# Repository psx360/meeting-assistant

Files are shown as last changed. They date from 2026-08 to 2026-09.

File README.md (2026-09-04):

# Meeting Assistant для Radxa ROCK 2F

Аппаратно-программный диктофон собраний: стереозапись с двух INMP441, управление кнопкой и OLED-платой HW-787AB, настройка Wi‑Fi по BLE, отложенная отправка при отсутствии сети, транскрибация на VPS и рассылка документов через Telegram/VK.

Репозиторий содержит исходники обеих частей системы и установщики для восстановления на чистых машинах. Секретные ключи, записи, база подписчиков и результаты встреч намеренно не входят в Git.

## Архитектура

1. Radxa записывает PulseAudio-источник INMP441 через FFmpeg в стерео Opus 48 кГц/64 кбит/с и делит поток на части по 10 минут.
2. Во время записи OLED показывает QR-код страницы подписки, таймер и уровень микрофона. Для остановки кнопку нужно удерживать не менее 1,5 секунды; подсказка на экране не занимает место.
3. Запись автоматически останавливается через 6 часов. После остановки QR остаётся на экране ещё 5 минут или до короткого нажатия кнопки.
4. После остановки части объединяются без повторного кодирования и помещаются в устойчивую локальную очередь. После скрытия QR OLED показывает процент подготовки и загрузки.
5. Таймер повторяет отправку на VPS; после скрытия QR OLED показывает «ОТПРАВКА» с процентами, а без сети — «ОЖИДАЕТ СЕТЬ», пока `.ready` не получил `.uploaded`.
6. VPS режет длинную запись на части по 20 минут и транскрибирует их моделью `gpt-4o-transcribe` с фиксированным языком `ru`.
7. Боты отправляют только два DOCX-файла: транскрибацию и протокол со сводкой. Постоянные подписчики получают все собрания, а перешедшие по QR — только выбранное.
8. В VK любое непустое текстовое сообщение включает постоянную подписку; команды отписки нет.

## Проверенная платформа

- Radxa ROCK 2F, Debian 12 (bookworm), Radxa kernel 6.1.43;
- 40-контактный GPIO-разъём;
- два цифровых микрофона INMP441 на SAI0/I2S0-M1;
- OLED/encoder HW-787AB, SSD1306-совместимый экран 128×64, I2C-адрес `0x3c`;
- отдельный Linux VPS с Debian/Ubuntu, Nginx и публичным HTTPS-доменом.

Другой образ ОС, нумерация GPIO или имя аудиоисточника могут потребовать адаптации констант.

## Подключение

Перед изменением проводов полностью отключайте питание. Номера ниже — физические номера контактов 40-pin разъёма.

### Два INMP441, стерео I2S0

| Сигнал INMP441 | Физический пин Radxa | Функция |
|---|---:|---|
| VDD обоих микрофонов | 17 | 3.3 V |
| GND обоих | 20 | GND |
| SCK/BCLK обоих | 12 | I2S0_SCLK_M1 / GPIO1_B5 |
| WS/LRCK обоих | 35 | I2S0_LRCK_M1 / GPIO1_B6 |
| SD обоих | 38 | I2S0_SDI_M1 / GPIO1_B7 |
| L/R первого | GND | левый канал |
| L/R второго | 3.3 V | правый канал |

Оба микрофона разделяют SCK, WS и SD; различаются только состоянием L/R.

### Кнопка записи

| Назначение | Подключение |
|---|---|
| Сигнальный контакт | физический пин 26, GPIO4_C1 (`gpiochip4`, line 17) |
| Подтяжка | 11 кОм от сигнала к 3.3 V |
| Второй контакт кнопки | GND |

Короткое нажатие запускает запись или убирает послесессионный QR-код. Во время записи короткое нажатие игнорируется; удержание не менее 1,5 секунды останавливает запись.

### HW-787AB

| Контакт платы | Физический пин Radxa | Назначение в ПО |
|---|---:|---|
| 3V3 | 1 или 17 | питание |
| GND | любой GND | земля |
| OLED_SDA | 32 | I2C0_SDA_M0 |
| OLED_SCL | 36 | I2C0_SCL_M0 |
| ENCODER_A | 11 | GPIO4_B7, line 15 |
| ENCODER_B | 13 | GPIO4_C0, line 16 |
| ENCODER_PUSH | 15 | GPIO4_C6, line 22 |
| BACK | 29 | GPIO4_B5, line 13 |
| CONFIRM | 31 | GPIO1_B0, `gpiochip1`, line 8 |

Пины `OLED_SDA/SCL` не совпадают с I2S и могут работать одновременно. WS2812B из окончательной конфигурации исключён: без преобразователя уровня 3.3→5 V управление было ненадёжным.

## Восстановление Radxa

На чистом Debian 12:

```bash
sudo apt-get update
sudo apt-get install -y git
git clone https://github.com/psx360/meeting-assistant.git
cd meeting-assistant
sudo ./install-radxa.sh
sudo nano /home/radxa/.config/meeting-upload.env
sudo reboot
```

В `meeting-upload.env` задайте публичный HTTPS URL VPS и общий `MEETING_API_TOKEN`. Установщик:

- ставит FFmpeg, SoX, PipeWire, BlueZ, NetworkManager, gpiod и зависимости Python;
- компилирует и подключает оба DT-overlay;
- устанавливает системные и пользовательские systemd-службы;
- включает watchdog Wi‑Fi и повторную отправку очереди;
- сохраняет резервную копию `extlinux.conf` как `extlinux.conf.meeting-assistant.bak`.

В меню OLED пункт «IP АДРЕС» показывает текущий IPv4-адрес Wi‑Fi интерфейса.

После перезагрузки проверьте:

```bash
arecord -l
pactl list short sources
i2cdetect -y 0
systemctl status recorder-controller oled-dashboard wifi-watchdog
systemctl --user status meeting-upload.timer
journalctl -f -u recorder-controller -u oled-dashboard
```

Ожидаемый источник: `alsa_input.platform-inmp441-sound.stereo-fallback`, OLED — `0x3c`.

Коэффициент программного усиления по умолчанию задаётся как `MIC_GAIN=4`. Значение можно изменить в BLE-форме; оно сохраняется в `/var/lib/meeting-recorder/settings.json` и применяется после перезагрузки и при каждом новом запуске записи.

## Восстановление VPS

```bash
sudo apt-get update
sudo apt-get install -y git
git clone https://github.com/psx360/meeting-assistant.git
cd meeting-assistant
sudo ./install-vps.sh
sudo nano /etc/meeting-assistant.env
sudo systemctl restart meeting-assistant meeting-worker
```

Заполните все поля из `vps.env.example`. `MEETING_API_TOKEN` должен побайтно совпадать со значением на Radxa. Затем замените `server_name _` в `/etc/nginx/sites-available/meeting-assistant` на домен и настройте HTTPS. Telegram и VK требуют публичный HTTPS callback URL.

Регистрация Telegram webhook после настройки `PUBLIC_BASE_URL`:

```bash
sudo python3 register-meeting-telegram-webhook.py
```

Для VK укажите callbacks:

- `https://ВАШ-ДОМЕН/vk/callback`;
- confirmation code, secret, group ID и community access token — в `/etc/meeting-assistant.env`.
- `VK_GROUP_SCREEN_NAME` можно задать коротким именем сообщества; иначе страница подписки использует `club<VK_GROUP_ID>`.

Проверка:

```bash
curl http://127.0.0.1:8090/health
systemctl status meeting-assistant meeting-worker nginx
journalctl -f -u meeting-assistant -u meeting-worker
```

Данные VPS находятся в `/var/lib/meeting-assistant`:

- `incoming/` — очередь;
- `completed/<meeting-id>/transcript-raw.txt` — исходное распознавание;
- `completed/<meeting-id>/transcript.txt` — исходная русская транскрипция без диаризации и пересказа;
- `completed/<meeting-id>/summary.txt` — структурированный протокол и сводка встречи.

Для подписчиков Telegram результат приходит в таком порядке:

1. DOCX с полной транскрибацией одним документом.
2. DOCX с протоколом и сводкой: тезисы, решения, организационные выводы, поручения и нерешённые вопросы — только если они были в разговоре.
3. Полный текст транскрибации, автоматически разбитый на несколько сообщений Telegram.
- `completed/<meeting-id>/protocol.txt` — отправленный протокол;
- `meeting-assistant.sqlite3` — подписчики и статусы рассылки.

Эти данные резервируются отдельно от Git.

## BLE-настройка

Нажмите энкодер на экране готовности и выберите режим BT. Устройство рекламируется как `Meeting Assistant`. Веб-форма находится в `bluefy-setup.html` и предназначена для открытия в iOS-браузере Bluefy. Она позволяет найти похожее имя Wi‑Fi, передать пароль или выбрать открытую сеть, изменить пороги речи/тишины и выполнить 10-секундный замер шума.

## Основные журналы

```bash
# Radxa: кнопка, запись, OLED, загрузка
journalctl -f -u recorder-controller -u oled-dashboard -u wifi-watchdog
journalctl --user -f -u audio-recorder -u meeting-upload

# VPS: приём, транскрибация и рассылка
journalctl -f -u meeting-assistant -u meeting-worker
```

## Безопасность и резервное копирование

Никогда не добавляйте в Git `.env`, `*.key`, базу SQLite и записи. Для полного аварийного восстановления отдельно сохраняйте:

- `/etc/meeting-assistant.env` на VPS;
- `/var/lib/meeting-assistant/meeting-assistant.sqlite3`;
- `/home/radxa/.config/meeting-upload.env`;
- при необходимости каталоги `completed/` и записи на Radxa.

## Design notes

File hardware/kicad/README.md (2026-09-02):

# KiCad hardware schematic

Editable schematic for the assembled Meeting Assistant. It documents wiring to the Radxa ROCK 2F header; it is not a custom PCB layout.

Open `meeting-assistant.kicad_pro` with KiCad 10, or regenerate the schematic with the Python API used by the KiCad MCP ecosystem:

```powershell
$env:KICAD_SYMBOL_DIR="C:\Program Files\KiCad\10.0\share\kicad\symbols"
python -m pip install kicad-sch-api
python generate_schematic.py
```

For a per-user KiCad installation, adjust `KICAD_SYMBOL_DIR` to `%LOCALAPPDATA%\Programs\KiCad\10.0\share\kicad\symbols`.

The net labels encode the actual physical-pin mapping. Equal labels are electrically connected even where a long wire is intentionally avoided for readability.

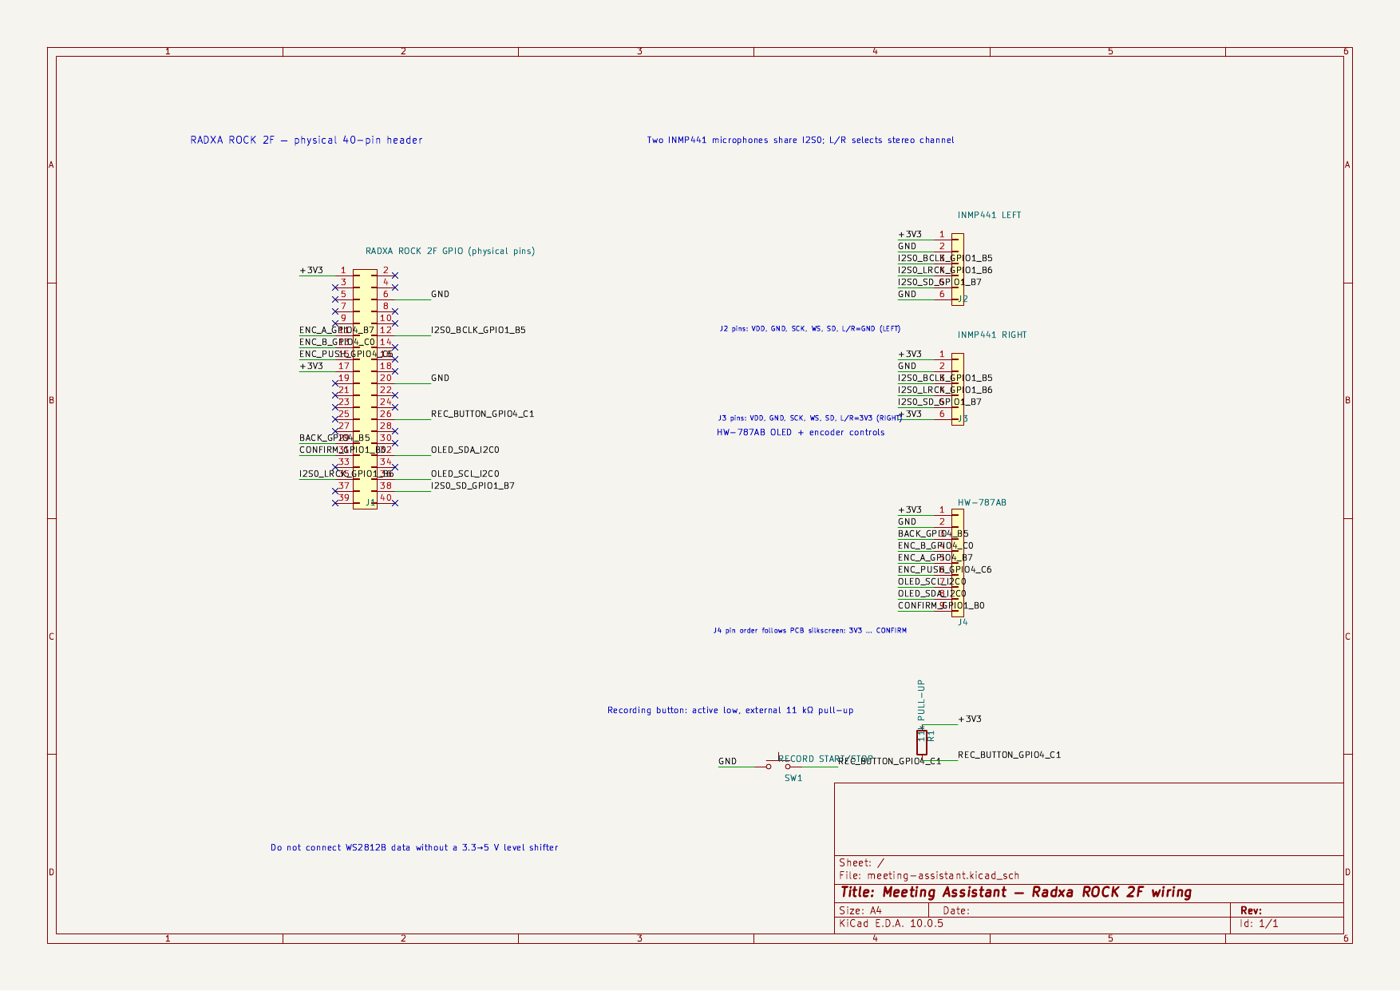
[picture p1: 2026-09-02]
hardware/kicad/export/meeting-assistant-preview.png

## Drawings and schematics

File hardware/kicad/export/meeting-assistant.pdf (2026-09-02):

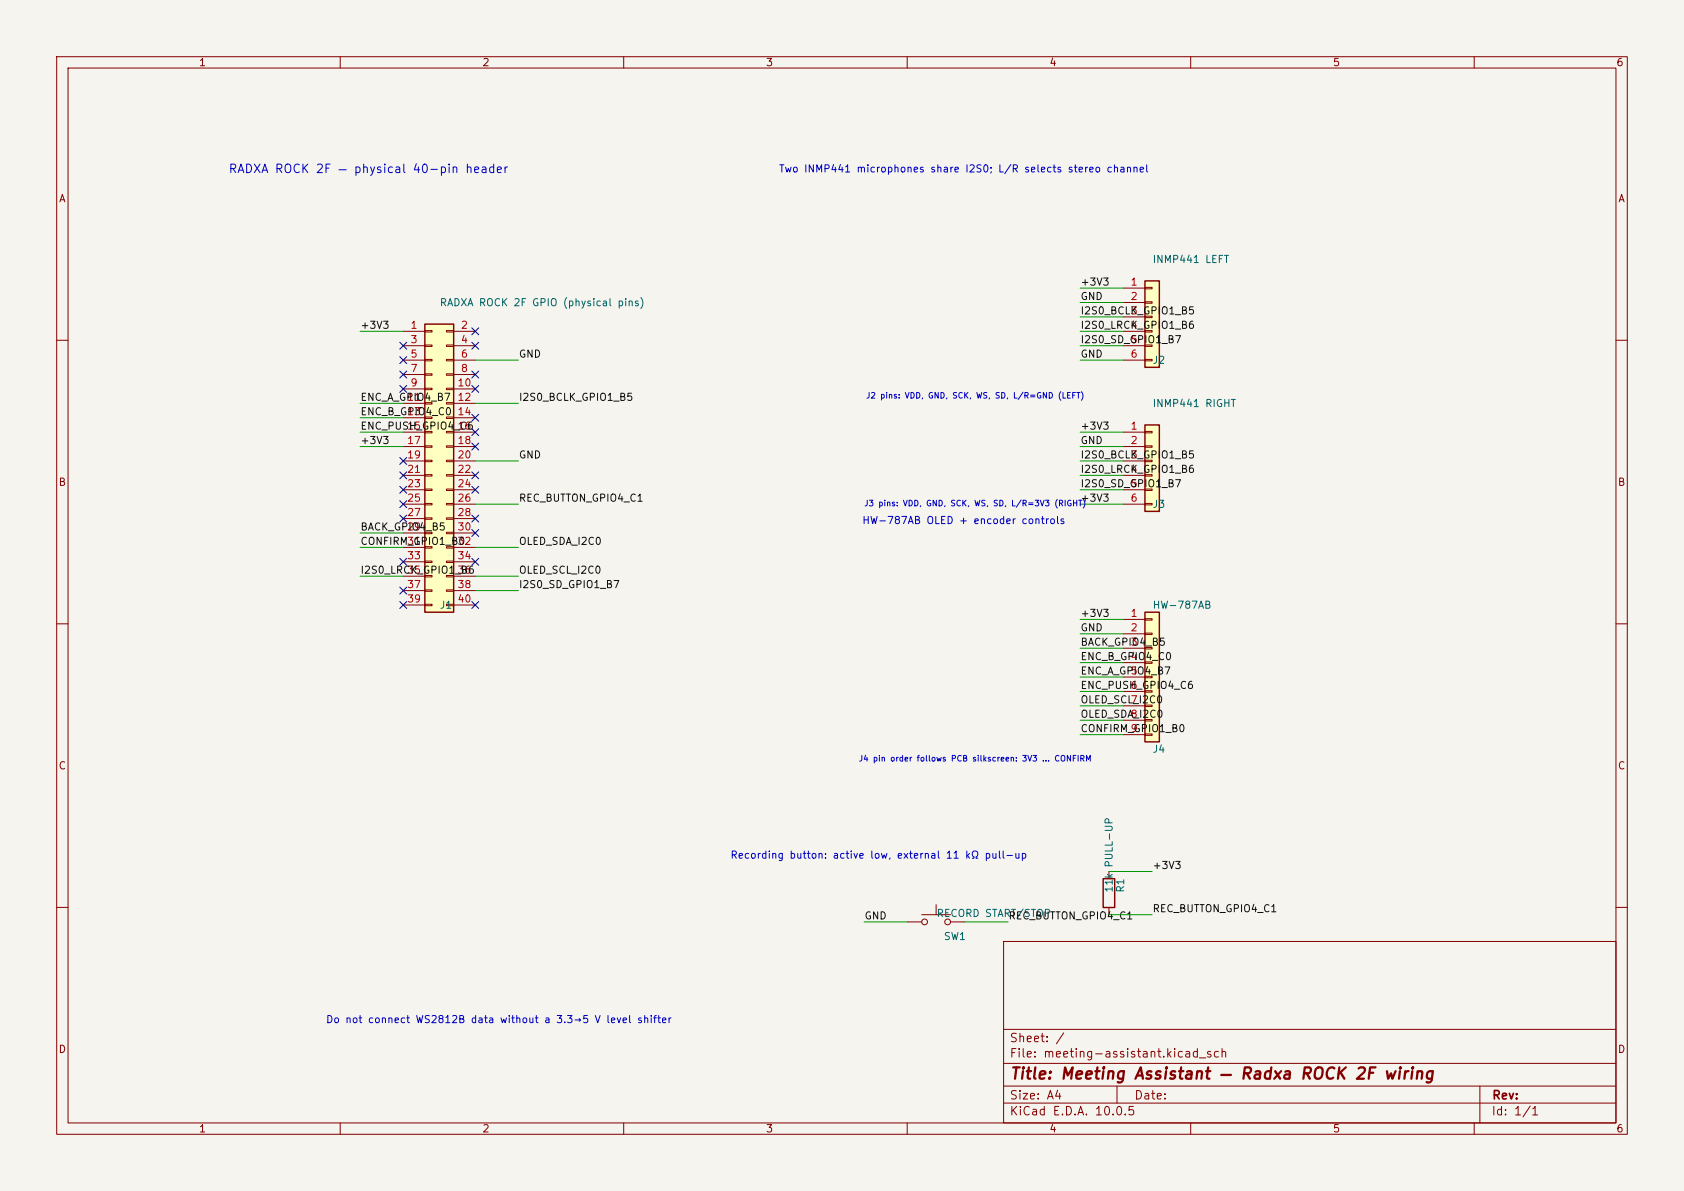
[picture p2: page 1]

J3 pins: VDD, GND, SCK, WS, SD, L/R=3V3 (RIGHT) Do not connect WS2812B data without a 3.3→5 V level shifter

J4 pin order follows PCB silkscreen: 3V3 … CONFIRM

Recording button: active low, external 11 kΩ pull-up

Sheet: /
File: meeting-assistant.kicad_sch
Title: Meeting Assistant — Radxa ROCK 2F wiring

Size: A4 | Rev:
KiCad E.D.A. 10.0.5 | Id: 1/1

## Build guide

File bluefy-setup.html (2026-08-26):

# Meeting Assistant

Настройка устройства по Bluetooth

## Bluetooth не подключён

Подключить устройствоОтключить

На диктофоне откройте меню и включите «BT СОПРЯЖЕНИЕ», затем выберите Meeting Assistant.

## Wi‑Fi

Название или похожая часть названия сети

Пароль

Открытая сеть, без пароля

Найти сетиСохранить и подключить

## Чувствительность к речи

Усиление микрофона

Сохранить усиление

Шум комнаты, dB

Порог речи, dB

Порог тишины, dB

Измерить шум 10 секундПрименить измеренноеСохранить порог

Во время измерения соблюдайте тишину. Порог речи устанавливается на 4 dB выше порога тишины.

## Состояние

Сначала подключите устройство.

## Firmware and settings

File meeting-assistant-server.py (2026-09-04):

#!/usr/bin/python3
import base64
import hashlib
import hmac
import html
import json
import importlib.util
import logging
import os
import re
import secrets
import sqlite3
import time
import urllib.parse
import urllib.request
import uuid
from http.server import BaseHTTPRequestHandler, ThreadingHTTPServer


HOST = "127.0.0.1"
PORT = int(os.environ.get("MEETING_ASSISTANT_PORT", "8090"))
DB_PATH = os.environ.get("MEETING_DB_PATH", "/var/lib/meeting-assistant/meeting-assistant.sqlite3")
INCOMING_DIR = os.environ.get("MEETING_INCOMING_DIR", "/var/lib/meeting-assistant/incoming")
MAX_UPLOAD_BYTES = 256 * 1024 * 1024
TELEGRAM_KEY = os.environ.get("TELEGRAM_KEY", "")
TELEGRAM_WEBHOOK_SECRET = os.environ.get("TELEGRAM_WEBHOOK_SECRET", "")
MEETING_API_TOKEN = os.environ.get("MEETING_API_TOKEN", "")
VK_CONFIRMATION_CODE = os.environ.get("VK_CONFIRMATION_CODE", "")
VK_SECRET = os.environ.get("VK_SECRET", "")
VK_GROUP_ID = os.environ.get("VK_GROUP_ID", "")
VK_GROUP_TOKEN = os.environ.get("VK_GROUP_TOKEN", "")
VK_GROUP_SCREEN_NAME = os.environ.get("VK_GROUP_SCREEN_NAME", "")
VK_API_VERSION = "5.199"
JOIN_SIGNATURE_BYTES = 12
JOIN_SIGNATURE_CHARS = len(base64.urlsafe_b64encode(b"\0" * JOIN_SIGNATURE_BYTES).decode().rstrip("="))

logging.basicConfig(level=logging.INFO, format="%(message)s")
log = logging.getLogger("meeting-assistant")

_documents_spec = importlib.util.spec_from_file_location(
    "meeting_documents", os.path.join(os.path.dirname(__file__), "meeting-documents.py")
)
meeting_documents = importlib.util.module_from_spec(_documents_spec)
_documents_spec.loader.exec_module(meeting_documents)


def db_connect():
    connection = sqlite3.connect(DB_PATH, timeout=30)
    connection.execute("PRAGMA journal_mode=WAL")
    connection.execute("PRAGMA busy_timeout=30000")
    return connection


def init_db():
    os.makedirs(INCOMING_DIR, exist_ok=True)
    with db_connect() as db:
        db.executescript(
            """
            CREATE TABLE IF NOT EXISTS subscribers (
                platform TEXT NOT NULL,
                recipient_id TEXT NOT NULL,
                active INTEGER NOT NULL DEFAULT 1,
                subscribed_at INTEGER NOT NULL,
                updated_at INTEGER NOT NULL,
                PRIMARY KEY (platform, recipient_id)
            );
            CREATE TABLE IF NOT EXISTS broadcasts (
                meeting_id TEXT PRIMARY KEY,
                title TEXT NOT NULL,
                transcript TEXT NOT NULL DEFAULT '',
                protocol TEXT NOT NULL,
                created_at INTEGER NOT NULL
            );
            CREATE TABLE IF NOT EXISTS deliveries (
                meeting_id TEXT NOT NULL,
                platform TEXT NOT NULL,
                recipient_id TEXT NOT NULL,
                status TEXT NOT NULL,
                error TEXT,
                updated_at INTEGER NOT NULL,
                PRIMARY KEY (meeting_id, platform, recipient_id)
            );
            CREATE TABLE IF NOT EXISTS meeting_subscriptions (
                meeting_id TEXT NOT NULL,
                platform TEXT NOT NULL,
                recipient_id TEXT NOT NULL,
                active INTEGER NOT NULL DEFAULT 1,
                subscribed_at INTEGER NOT NULL,
                updated_at INTEGER NOT NULL,
                PRIMARY KEY (meeting_id, platform, recipient_id)
            );
            """
        )
        broadcast_columns = {row[1] for row in db.execute("PRAGMA table_info(broadcasts)")}
        if "transcript" not in broadcast_columns:
            db.execute("ALTER TABLE broadcasts ADD COLUMN transcript TEXT NOT NULL DEFAULT ''")


def set_subscription(platform, recipient_id, active):
    now = int(time.time())
    with db_connect() as db:
        db.execute(
            """INSERT INTO subscribers(platform, recipient_id, active, subscribed_at, updated_at)
               VALUES (?, ?, ?, ?, ?)
               ON CONFLICT(platform, recipient_id) DO UPDATE
               SET active=excluded.active, updated_at=excluded.updated_at""",
            (platform, str(recipient_id), int(active), now, now),
        )
    log.info("SUBSCRIPTION platform=%s recipient=%s active=%s", platform, recipient_id, str(active).lower())


def set_meeting_subscription(meeting_id, platform, recipient_id, active=True):
    now = int(time.time())
    with db_connect() as db:
        db.execute(
            """INSERT INTO meeting_subscriptions(meeting_id, platform, recipient_id, active, subscribed_at, updated_at)
               VALUES (?, ?, ?, ?, ?, ?)
               ON CONFLICT(meeting_id, platform, recipient_id) DO UPDATE
               SET active=excluded.active, updated_at=excluded.updated_at""",
            (meeting_id, platform, str(recipient_id), int(active), now, now),
        )
    log.info(
        "MEETING_SUBSCRIPTION meeting=%s platform=%s recipient=%s active=%s",
        meeting_id, platform, recipient_id, str(active).lower(),
    )
    if active:
        deliver_existing_meeting(meeting_id, platform, str(recipient_id))


def join_payload(meeting_id):
    if not MEETING_API_TOKEN or not re.fullmatch(r"[A-Za-z0-9._-]{1,200}", meeting_id):
        return ""
    digest = hmac.new(MEETING_API_TOKEN.encode(), meeting_id.encode(), hashlib.sha256).digest()
    signature = base64.urlsafe_b64encode(digest[:JOIN_SIGNATURE_BYTES]).decode().rstrip("=")
    return f"m_{meeting_id}_{signature}"


def meeting_id_from_payload(payload):
    if not re.fullmatch(r"m_[A-Za-z0-9._-]{1,240}", payload or ""):
        return ""
    value = payload[2:]
    separator = len(value) - JOIN_SIGNATURE_CHARS - 1
    if separator <= 0 or value[separator] != "_":
        return ""
    meeting_id = value[:separator]
    expected = join_payload(meeting_id)
    return meeting_id if expected and secrets.compare_digest(payload, expected) else ""


def chunks(text, limit=3500):
    text = text.strip()
    while text:
        if len(text) <= limit:
            yield text
            return
        split_at = text.rfind("\n", 0, limit)
        if split_at < limit // 2:
            split_at = text.rfind(" ", 0, limit)
        if split_at < limit // 2:
            split_at = limit
        yield text[:split_at].rstrip()
        text = text[split_at:].lstrip()


def post_form(url, fields):
    payload = urllib.parse.urlencode(fields).encode()
    request = urllib.request.Request(url, data=payload, method="POST")
    with urllib.request.urlopen(request, timeout=20) as response:
        return json.load(response)


def post_multipart(url, fields, file_field, filename, content, content_type):
    boundary = "----meeting-" + uuid.uuid4().hex
    body = bytearray()
    for name, value in fields.items():
        body.extend(f"--{boundary}\r\nContent-Disposition: form-data; name=\"{name}\"\r\n\r\n{value}\r\n".encode("utf-8"))
    body.extend(
        f"--{boundary}\r\nContent-Disposition: form-data; name=\"{file_field}\"; filename=\"{filename}\"\r\n"
        f"Content-Type: {content_type}\r\n\r\n".encode("utf-8")
    )
    body.extend(content)
    body.extend(f"\r\n--{boundary}--\r\n".encode("ascii"))
    request = urllib.request.Request(
        url, data=body, headers={"Content-Type": f"multipart/form-data; boundary={boundary}"}, method="POST"
    )
    with urllib.request.urlopen(request, timeout=60) as response:
        return json.load(response)


def telegram(method, fields):
    if not TELEGRAM_KEY:
        raise RuntimeError("Telegram token is not configured")
    result = post_form(f"https://api.telegram.org/bot{TELEGRAM_KEY}/{method}", fields)
    if not result.get("ok"):
        raise RuntimeError(result.get("description", "Telegram API error"))
    return result


def telegram_send(chat_id, text):
    for part in chunks(text):
        telegram("sendMessage", {"chat_id": chat_id, "text": part})


def telegram_document(chat_id, filename, content):
    if not TELEGRAM_KEY:
        raise RuntimeError("Telegram token is not configured")
    result = post_multipart(
        f"https://api.telegram.org/bot{TELEGRAM_KEY}/sendDocument",
        {"chat_id": str(chat_id)}, "document", filename, content,
        "application/vnd.openxmlformats-officedocument.wordprocessingml.document",
    )
    if not result.get("ok"):
        raise RuntimeError(result.get("description", "Telegram API error"))
    return result


_telegram_username = ""


def telegram_bot_username():
    global _telegram_username
    if not _telegram_username:
        result = telegram("getMe", {})
        _telegram_username = str((result.get("result") or {}).get("username", "")).lstrip("@")
    return _telegram_username


def vk(method, fields):
    if not VK_GROUP_TOKEN:
        raise RuntimeError("VK group access token is not configured")
    fields.update({"access_token": VK_GROUP_TOKEN, "v": VK_API_VERSION})
    result = post_form(f"https://api.vk.com/method/{method}", fields)
    if "error" in result:
        raise RuntimeError(result["error"].get("error_msg", "VK API error"))
    return result


def vk_send(peer_id, text):
    for part in chunks(text):
        vk("messages.send", {"peer_id": peer_id, "random_id": secrets.randbelow(2_147_483_647), "message": part})


def vk_document_attachment(peer_id, filename, content):
    file_token = ""
    for attempt in range(1, 4):
        upload = vk("docs.getMessagesUploadServer", {"peer_id": peer_id, "type": "doc"}).get("response") or {}
        upload_url = upload.get("upload_url", "")
        if not upload_url:
            raise RuntimeError("VK did not return a document upload URL")
        uploaded = post_multipart(
            upload_url, {}, "file", filename, content,
            "application/vnd.openxmlformats-officedocument.wordprocessingml.document",
        )
        file_token = uploaded.get("file", "")
        if file_token:
            break
        log.warning("VK_DOCUMENT_UPLOAD_RETRY peer=%s file=%s attempt=%d", peer_id, safe_filename(filename), attempt)
        if attempt < 3:
            time.sleep(0.5 * attempt)
    if not file_token:
        raise RuntimeError("VK document upload did not return a file token after 3 attempts")
    saved = vk("docs.save", {"file": file_token, "title": filename}).get("response")
    if isinstance(saved, list):
        document = saved[0] if saved else {}
    elif isinstance(saved, dict) and isinstance(saved.get("doc"), dict):
        document = saved["doc"]
    else:
        document = saved or {}
    owner_id, document_id = document.get("owner_id"), document.get("id")
    if owner_id is None or document_id is None:
        raise RuntimeError("VK docs.save did not return a document identifier")
    attachment = f"doc{owner_id}_{document_id}"
    if document.get("access_key"):
        attachment += f"_{document['access_key']}"
    return attachment


def vk_send_documents(peer_id, documents):
    attachments = [vk_document_attachment(peer_id, filename, content) for filename, content in documents]
    vk("messages.send", {
        "peer_id": peer_id,
        "random_id": secrets.randbelow(2_147_483_647),
        "attachment": ",".join(attachments),
    })


def subscription_command(text):
    command = text.strip().lower().split(maxsplit=1)[0] if text.strip() else ""
    if "@" in command:
        command = command.split("@", 1)[0]
    if command in {"/start", "/subscribe", "подписаться", "старт", "start", "subscribe"}:
        return True
    if command in {"/stop", "/unsubscribe", "отписаться", "стоп", "stop", "unsubscribe"}:
        return False
    return None


def telegram_meeting_payload(text):
    parts = text.strip().split(maxsplit=1)
    if len(parts) != 2:
        return ""
    command = parts[0].lower().split("@", 1)[0]
    return parts[1].strip() if command == "/start" else ""


def handle_telegram(update):
    message = update.get("message") or {}
    chat_id = (message.get("chat") or {}).get("id")
    if not chat_id:
        return
    text = message.get("text", "")
    payload = telegram_meeting_payload(text)
    if payload:
        meeting_id = meeting_id_from_payload(payload)
        if meeting_id:
            set_meeting_subscription(meeting_id, "telegram", chat_id)
            telegram_send(chat_id, "Вы подписаны только на документы этого собрания.")
        else:
            telegram_send(chat_id, "Ссылка на собрание недействительна.")
        return
    command = subscription_command(text)
    if command is True:
        set_subscription("telegram", chat_id, True)
        telegram_send(chat_id, "Вы подписаны на протоколы собраний. Для отмены: /unsubscribe")
    elif command is False:
        set_subscription("telegram", chat_id, False)
        telegram_send(chat_id, "Подписка на протоколы собраний отключена. Для возобновления: /subscribe")
    else:
        telegram_send(chat_id, "Команды: /subscribe — получать протоколы, /unsubscribe — отключить рассылку.")


def handle_vk(event):
    event_type = event.get("type", "")
    obj = event.get("object") or {}
    if event_type == "message_allow":
        user_id = obj.get("user_id")
        if user_id:
            set_subscription("vk", user_id, True)
        return
    if event_type == "message_deny":
        user_id = obj.get("user_id")
        if user_id:
            set_subscription("vk", user_id, False)
        return
    if event_type != "message_new":
        return
    message = obj.get("message") or {}
    peer_id = message.get("peer_id") or message.get("from_id")
    if not peer_id:
        return
    meeting_id = meeting_id_from_payload(str(message.get("ref", "")))
    if meeting_id:
        set_meeting_subscription(meeting_id, "vk", peer_id)
        vk_send(peer_id, "Вы подписаны только на документы этого собрания.")
        return
    text = str(message.get("text", "")).strip()
    if text:
        set_subscription("vk", peer_id, True)
        vk_send(peer_id, "Вы подписаны на протоколы собраний.")
    else:
        vk_send(peer_id, "Отправьте любое текстовое сообщение, чтобы подписаться на протоколы собраний.")


def safe_filename(value):
    value = re.sub(r"[^A-Za-zА-Яа-яЁё0-9._ -]+", "_", value).strip(" ._")
    return value[:100] or "Собрание"


def meeting_page(payload):
    meeting_id = meeting_id_from_payload(payload)
    if not meeting_id:
        return 404, "Ссылка на собрание недействительна."
    try:
        telegram_username = telegram_bot_username()
    except Exception:
        log.exception("TELEGRAM_USERNAME_LOOKUP_FAILED")
        telegram_username = ""
    vk_name = VK_GROUP_SCREEN_NAME.strip().lstrip("@") or (f"club{VK_GROUP_ID}" if VK_GROUP_ID else "")
    telegram_url = f"https://t.me/{telegram_username}?start={urllib.parse.quote(payload)}" if telegram_username else ""
    vk_url = (
        f"https://vk.me/{urllib.parse.quote(vk_name)}?"
        + urllib.parse.urlencode({"ref": payload, "ref_source": "meeting_qr"})
        if vk_name else ""
    )
    buttons = []
    if telegram_url:
        buttons.append(f'<a class="button telegram" href="{html.escape(telegram_url, quote=True)}">Подписаться в Telegram</a>')
    if vk_url:
        buttons.append(f'<a class="button vk" href="{html.escape(vk_url, quote=True)}">Подписаться во ВКонтакте</a>')
    if not buttons:
        buttons.append('<p class="error">Ссылки на ботов пока не настроены.</p>')
    page = f"""<!doctype html>
<html lang="ru"><head><meta charset="utf-8"><meta name="viewport" content="width=device-width,initial-scale=1">
<meta name="theme-color" content="#14213d"><title>Подписка на собрание</title>
<style>
:root{{font-family:-apple-system,BlinkMacSystemFont,"Segoe UI",sans-serif;color:#152238;background:#eef2f7}}
*{{box-sizing:border-box}}body{{margin:0;padding:24px 16px}}main{{max-width:520px;margin:auto;background:#fff;border-radius:20px;padding:26px;box-shadow:0 12px 35px #1e293b20}}
h1{{margin:0 0 10px;font-size:27px}}p{{line-height:1.5;color:#526174}}.meeting{{font-family:ui-monospace,monospace;background:#f1f5f9;border-radius:10px;padding:10px 12px;word-break:break-all}}
.button{{display:block;margin:13px 0;padding:15px 18px;border-radius:12px;color:#fff;text-decoration:none;text-align:center;font-weight:700}}.telegram{{background:#229ed9}}.vk{{background:#0077ff}}.note{{font-size:13px}}.error{{color:#b91c1c}}
</style></head><body><main><h1>Документы собрания</h1>
<p>Выберите бот. Подписка действует только для этого собрания: после обработки бот пришлёт протокол и транскрибацию в DOCX.</p>
<div class="meeting">{html.escape(meeting_id)}</div>{''.join(buttons)}
<p class="note">В Telegram нажмите «Старт». Во ВКонтакте откройте диалог и отправьте любое сообщение — метка собрания передастся боту автоматически.</p>
</main></body></html>"""
    return 200, page


def document_payloads(title, transcript, summary):
    stem = safe_filename(title)
    return [
        (f"{stem} - транскрибация.docx", meeting_documents.build_docx(f"{title} — транскрибация", transcript)),
        (f"{stem} - протокол и сводка.docx", meeting_documents.build_docx(f"{title} — протокол и сводка", summary, structured=True)),
    ]


def claim_delivery(meeting_id, platform, recipient_id):
    with db_connect() as db:
        result = db.execute(
            """INSERT INTO deliveries(meeting_id, platform, recipient_id, status, error, updated_at)
               VALUES (?, ?, ?, 'sending', NULL, ?)
               ON CONFLICT(meeting_id, platform, recipient_id) DO UPDATE
               SET status='sending', error=NULL, updated_at=excluded.updated_at
               WHERE deliveries.status='failed'""",
            (meeting_id, platform, str(recipient_id), int(time.time())),
        )
        return result.rowcount == 1


def finish_delivery(meeting_id, platform, recipient_id, status, error=None):
    with db_connect() as db:
        db.execute(
            """UPDATE deliveries SET status=?, error=?, updated_at=?
               WHERE meeting_id=? AND platform=? AND recipient_id=?""",
            (status, error, int(time.time()), meeting_id, platform, str(recipient_id)),
        )


def send_document_payloads(platform, recipient_id, documents):
    if platform == "telegram":
        for filename, content in documents:
            telegram_document(recipient_id, filename, content)
    elif platform == "vk":
        vk_send_documents(recipient_id, documents)
    else:
        raise RuntimeError("unknown platform")


def deliver_existing_meeting(meeting_id, platform, recipient_id):
    with db_connect() as db:
        completed = db.execute(
            "SELECT title, transcript, protocol FROM broadcasts WHERE meeting_id=?",
            (meeting_id,),
        ).fetchone()
    if not completed or not completed[1] or not claim_delivery(meeting_id, platform, recipient_id):
        return False
    try:
        send_document_payloads(platform, recipient_id, document_payloads(*completed))
        finish_delivery(meeting_id, platform, recipient_id, "sent")
        log.info("LATE_DELIVERY_FINISHED meeting=%s platform=%s recipient=%s", meeting_id, platform, recipient_id)
        return True
    except Exception as exc:
        error = str(exc)[:500]
        finish_delivery(meeting_id, platform, recipient_id, "failed", error)
        log.error("LATE_DELIVERY_FAILED meeting=%s platform=%s recipient=%s error=%s", meeting_id, platform, recipient_id, error)
        return False


def broadcast(meeting_id, title, transcript, summary):
    now = int(time.time())
    with db_connect() as db:
        existing = db.execute("SELECT 1 FROM broadcasts WHERE meeting_id=?", (meeting_id,)).fetchone()
        if existing:
            return {"duplicate": True, "sent": 0, "failed": 0}
        db.execute(
            "INSERT INTO broadcasts(meeting_id, title, transcript, protocol, created_at) VALUES (?, ?, ?, ?, ?)",
            (meeting_id, title, transcript, summary, now),
        )
        recipients = db.execute(
            """SELECT platform, recipient_id FROM subscribers WHERE active=1
               UNION
               SELECT platform, recipient_id FROM meeting_subscriptions WHERE meeting_id=? AND active=1
               ORDER BY platform, recipient_id""",
            (meeting_id,),
        ).fetchall()

    documents = document_payloads(title, transcript, summary)
    sent = failed = 0
    for platform, recipient_id in recipients:
        if not claim_delivery(meeting_id, platform, recipient_id):
            continue
        try:
            send_document_payloads(platform, recipient_id, documents)
            status, error = "sent", None
            sent += 1
        except Exception as exc:
            status, error = "failed", str(exc)[:500]
            failed += 1
            log.error("DELIVERY_FAILED meeting=%s platform=%s recipient=%s error=%s", meeting_id, platform, recipient_id, error)
        finish_delivery(meeting_id, platform, recipient_id, status, error)
    log.info("BROADCAST_FINISHED meeting=%s sent=%d failed=%d", meeting_id, sent, failed)
    return {"duplicate": False, "sent": sent, "failed": failed}
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

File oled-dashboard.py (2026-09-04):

#!/usr/bin/python3
import array, fcntl, glob, json, math, os, signal, subprocess, threading, time
import gpiod
try:import qrcode
except ImportError:qrcode=None
I2C_DEV="/dev/i2c-0"; I2C_ADDR=0x3C; STATE_FILE="/run/ai-recorder-state"; LEVEL_FILE="/run/ai-recorder-audio-level"
UPLOAD_PROGRESS_FILE="/run/user/1000/meeting-upload-progress.json"; AUTO_STOP_SECONDS=6*3600; AUTO_STOP_WARNING_SECONDS=15*60
MEETING_DISPLAY_FILE="/run/user/1000/meeting-display.json"
MEETING_DISPLAY_DISMISSED_FILE="/run/user/1000/meeting-display-dismissed"
SOURCE="alsa_input.platform-inmp441-sound.stereo-fallback"
DEFAULT_MIC_GAIN=float(os.environ.get("MIC_GAIN","4"))
SETTINGS_FILE="/var/lib/meeting-recorder/settings.json"
FONT={
" ":[0,0,0,0,0],"-":[8,8,8,8,8],".":[0,0,0,96,96],":":[0,54,54,0,0],"/":[64,32,16,8,4],"!":[0,0,95,0,0],"?":[2,1,81,9,6],
"0":[62,81,73,69,62],"1":[0,66,127,64,0],"2":[66,97,81,73,70],"3":[33,65,69,75,49],"4":[24,20,18,127,16],"5":[39,69,69,69,57],"6":[60,74,73,73,48],"7":[1,113,9,5,3],"8":[54,73,73,73,54],"9":[6,73,73,41,30],
"A":[126,17,17,17,126],"B":[127,73,73,73,54],"C":[62,65,65,65,34],"D":[127,65,65,34,28],"E":[127,73,73,73,65],"F":[127,9,9,9,1],"G":[62,65,73,73,122],"H":[127,8,8,8,127],"I":[0,65,127,65,0],"J":[32,64,65,63,1],"K":[127,8,20,34,65],"L":[127,64,64,64,64],"M":[127,2,12,2,127],"N":[127,4,8,16,127],"O":[62,65,65,65,62],"P":[127,9,9,9,6],"Q":[62,65,81,33,94],"R":[127,9,25,41,70],"S":[38,73,73,73,50],"T":[1,1,127,1,1],"U":[63,64,64,64,63],"V":[31,32,64,32,31],"W":[63,64,56,64,63],"X":[99,20,8,20,99],"Y":[3,4,120,4,3],"Z":[97,81,73,69,67]}
FONT.update({
"А":FONT["A"],"Б":[127,73,73,73,49],"В":FONT["B"],"Г":[127,1,1,1,1],
"Д":[96,62,33,33,127],"Е":FONT["E"],"Ё":[125,84,84,84,69],"Ж":[119,8,127,8,119],
"З":[34,65,73,73,54],"И":[127,32,16,8,127],"Й":[124,33,17,9,124],"К":FONT["K"],
"Л":[64,62,1,1,127],"М":FONT["M"],"Н":FONT["H"],"О":FONT["O"],
"П":[127,1,1,1,127],"Р":FONT["P"],"С":FONT["C"],"Т":FONT["T"],
"У":[7,72,72,72,63],"Ф":[28,34,127,34,28],"Х":FONT["X"],"Ц":[63,32,32,127,96],
"Ч":[15,8,8,8,127],"Ш":[127,64,127,64,127],"Щ":[63,32,63,32,127],
"Ъ":[1,127,72,72,48],"Ы":[127,72,48,0,127],"Ь":[127,72,72,72,48],
"Э":[34,73,73,73,62],"Ю":[127,8,62,65,62],"Я":[70,41,25,9,127]})
FONT[">"]=[0,65,34,20,8]
FONT["*"]=[20,8,62,8,20]
FONT["%"]=[99,19,8,100,99]
class Display:
 def __init__(self):
  self.fd=os.open(I2C_DEV,os.O_RDWR); fcntl.ioctl(self.fd,0x0703,I2C_ADDR); self.buf=bytearray(1024)
  self.cmd(0xAE,0xD5,0x80,0xA8,0x3F,0xD3,0,0x40,0xAD,0x8B,0xA1,0xC8,0xDA,0x12,0x81,0x45,0xD9,0x22,0xDB,0x35,0xA4,0xA6,0xAF)
 def cmd(self,*v):
  for i in range(0,len(v),16): os.write(self.fd,bytes([0])+bytes(v[i:i+16]))
 def clear(self): self.buf[:]=b'\0'*1024
 def pixel(self,x,y,on=True):
  if 0<=x<128 and 0<=y<64:
   index=(y//8)*128+x;mask=1<<(y&7)
   if on:self.buf[index]|=mask
   else:self.buf[index]&=~mask
 def text(self,x,y,s,scale=1):
  for ch in s.upper():
   for gx,col in enumerate(FONT.get(ch,FONT["?"])):
    for gy in range(7):
     if col&(1<<gy):
      for dx in range(scale):
       for dy in range(scale): self.pixel(x+gx*scale+dx,y+gy*scale+dy)
   x+=6*scale
 def centered(self,y,s,scale=1): self.text(max(0,(128-len(s)*6*scale+scale)//2),y,s,scale)
 def line(self,x0,y0,x1,y1=None):
  if y1 is None:x1,y1=x0,x1
  dx=abs(x1-x0);sx=1 if x0<x1 else -1;dy=-abs(y1-y0);sy=1 if y0<y1 else -1;error=dx+dy
  while True:
   self.pixel(x0,y0)
   if x0==x1 and y0==y1:break
   twice=2*error
   if twice>=dy:error+=dy;x0+=sx
   if twice<=dx:error+=dx;y0+=sy
 def qr(self,value,x=0,y=0,max_size=64):
  if qrcode is None:return False
  code=qrcode.QRCode(error_correction=qrcode.constants.ERROR_CORRECT_L,box_size=1,border=2)
  code.add_data(value);code.make(fit=True);matrix=code.get_matrix();modules=len(matrix)
  scale=max(1,max_size//modules);size=modules*scale;ox=x+(max_size-size)//2;oy=y+(max_size-size)//2
  for px in range(ox,ox+size):
   for py in range(oy,oy+size):self.pixel(px,py,True)
  for row,line in enumerate(matrix):
   for column,dark in enumerate(line):
    if dark:
     for dx in range(scale):
      for dy in range(scale):self.pixel(ox+column*scale+dx,oy+row*scale+dy,False)
  return True
 def show(self):
  for p in range(8):
   self.cmd(0xB0+p,2,0x10); row=self.buf[p*128:(p+1)*128]
   for i in range(0,128,16): os.write(self.fd,bytes([0x40])+row[i:i+16])
class Meter:
 def __init__(self): self.db=-90.; self.running=False; self.proc=None; self.lock=threading.Lock();self.gain=DEFAULT_MIC_GAIN
 def start(self,gain):
  self.gain=gain
  if not self.running:self.running=True;threading.Thread(target=self._run,daemon=True).start()
 def stop(self):
  self.running=False
  if self.proc:
   try:self.proc.terminate()
   except ProcessLookupError:pass
  self.proc=None; self.db=-90.
 def _run(self):
  env=os.environ.copy(); env.update(XDG_RUNTIME_DIR="/run/user/1000",DBUS_SESSION_BUS_ADDRESS="unix:path=/run/user/1000/bus")
  try:
   self.proc=subprocess.Popen(["runuser","-u","radxa","--","ffmpeg","-nostdin","-hide_banner","-loglevel","error","-f","pulse","-i",SOURCE,"-af",f"volume={self.gain:g}","-ac","1","-ar","8000","-f","s16le","pipe:1"],stdout=subprocess.PIPE,stderr=subprocess.DEVNULL,env=env)
   while self.running:
    raw=self.proc.stdout.read(1600)
    if not raw:break
    a=array.array('h',raw); rms=math.sqrt(sum(v*v for v in a)/max(1,len(a))); db=20*math.log10(max(1,rms)/32768.)
    with self.lock:self.db=max(-90.,min(0.,db))
    try:
     with open(LEVEL_FILE,"w",encoding="ascii") as f:f.write(f"{time.time():.3f} {self.db:.2f}\n")
    except OSError:pass
  except Exception:self.db=-90.
  finally:self.running=False
 def value(self):
  with self.lock:return self.db
class Controls:
 def __init__(self):
  self.chip4=gpiod.Chip("gpiochip4");self.chip1=gpiod.Chip("gpiochip1");self.lines=[];self.last={}
  self.encoder_a=self._event(self.chip4,15,"oled-encoder-a")
  self.encoder_b=self.chip4.get_line(16);self.encoder_b.request(consumer="oled-encoder-b",type=gpiod.LINE_REQ_DIR_IN)
  self.knob=self._event(self.chip4,22,"oled-encoder-button")
  self.back=self._event(self.chip4,13,"oled-back")
  self.confirm=self._event(self.chip1,8,"oled-confirm")
 def _event(self,chip,offset,name):
  line=chip.get_line(offset);line.request(consumer=name,type=gpiod.LINE_REQ_EV_FALLING_EDGE);self.lines.append(line);return line
 def poll(self):
  result=[];now=time.monotonic()
  for name,line in (("ROTATE",self.encoder_a),("KNOB",self.knob),("BACK",self.back),("CONFIRM",self.confirm)):
   if line.event_wait(sec=0,nsec=0):
    line.event_read()
    while line.event_wait(sec=0,nsec=0):line.event_read()
    debounce=.22 if name=="ROTATE" else .50
    if now-self.last.get(name,0)>debounce:
     self.last[name]=now
     if name=="ROTATE":result.append("RIGHT" if self.encoder_b.get_value() else "LEFT")
     else:result.append(name)
  return result
 def close(self):
  for line in self.lines:
   try:line.release()
   except Exception:pass
  try:self.encoder_b.release()
  except Exception:pass
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

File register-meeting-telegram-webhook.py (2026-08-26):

#!/usr/bin/python3
import json
import urllib.parse
import urllib.request


values = {}
with open("/etc/meeting-assistant.env", encoding="utf-8") as source:
    for raw_line in source:
        line = raw_line.strip()
        if line and not line.startswith("#") and "=" in line:
            key, value = line.split("=", 1)
            values[key] = value.strip().strip("\"'")

token = values["TELEGRAM_KEY"]
secret = values["TELEGRAM_WEBHOOK_SECRET"]
base_url = values["PUBLIC_BASE_URL"].rstrip("/")
fields = urllib.parse.urlencode(
    {
        "url": base_url + "/telegram/webhook",
        "secret_token": secret,
        "allowed_updates": json.dumps(["message"]),
        "drop_pending_updates": "true",
    }
).encode()
request = urllib.request.Request(f"https://api.telegram.org/bot{token}/setWebhook", data=fields)
with urllib.request.urlopen(request, timeout=20) as response:
    result = json.load(response)
print(f"WEBHOOK_OK={result.get('ok', False)}")
print(f"DESCRIPTION={result.get('description', '')}")

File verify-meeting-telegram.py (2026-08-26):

#!/usr/bin/python3
import json
import urllib.request

values = {}
with open("/root/meeting_assistant.key", encoding="utf-8") as source:
    for raw_line in source:
        line = raw_line.strip()
        if line and not line.startswith("#") and "=" in line:
            key, value = line.split("=", 1)
            values[key.strip()] = value.strip().strip("\"'")

token = values.get("TELEGRAM_KEY", "")
if not token:
    raise SystemExit("TELEGRAM_KEY_MISSING")

with urllib.request.urlopen(f"https://api.telegram.org/bot{token}/getMe", timeout=15) as response:
    data = json.load(response)
result = data.get("result", {})
print(f"TELEGRAM_OK={data.get('ok', False)}")
print(f"BOT_ID={result.get('id', '')}")
print(f"BOT_USERNAME={result.get('username', '')}")

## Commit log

2026-09-02 Add reproducible KiCad hardware schematic
    [meeting-assistant.kicad_sch]
2026-09-04 Calibrate and smooth microphone level display
2026-09-04 Fix microphone UI and preserve short recording presses
    [oled-dashboard.py, recorder-controller.py]
